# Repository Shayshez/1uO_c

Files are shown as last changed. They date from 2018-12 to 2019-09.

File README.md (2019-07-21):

1u Version (Pulp Logic) of Ornament & Crime, 30HP.

For pcb's and panels: https://pushermanproductions.com/product/plum-audio-1u-ornament-crime-pcb-and-aluminium-panel/

Teensy Assembling (with Supervisor):https://youtu.be/IDsQhNgkL-Y

OLED Screen Assembling: https://youtu.be/ywh_6SPNrSg 

Need help?
Join "Plum Audio DIY first aid" Group:
https://www.facebook.com/groups/PlumAudioDIY

Looking for assembled module?
https://www.plum-audio.com/product-page/1uo-c

** Note for Pusherman v1.1 Pcb's - There is minor silk screen mistake - The Inputs and Outputs not numberd correctly. 
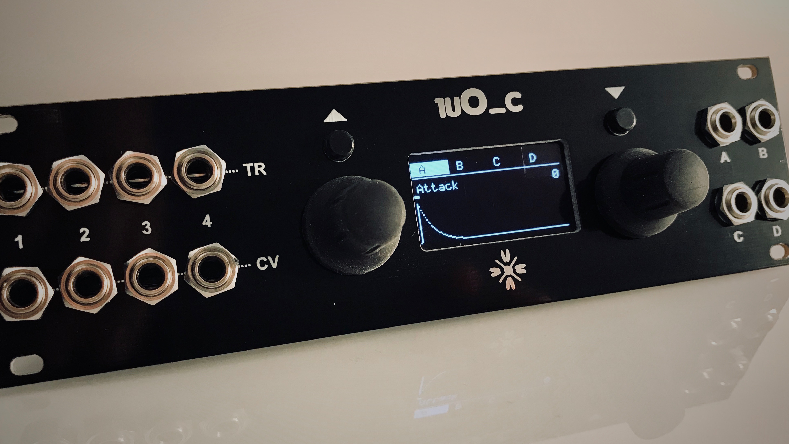
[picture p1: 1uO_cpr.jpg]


1uO_c

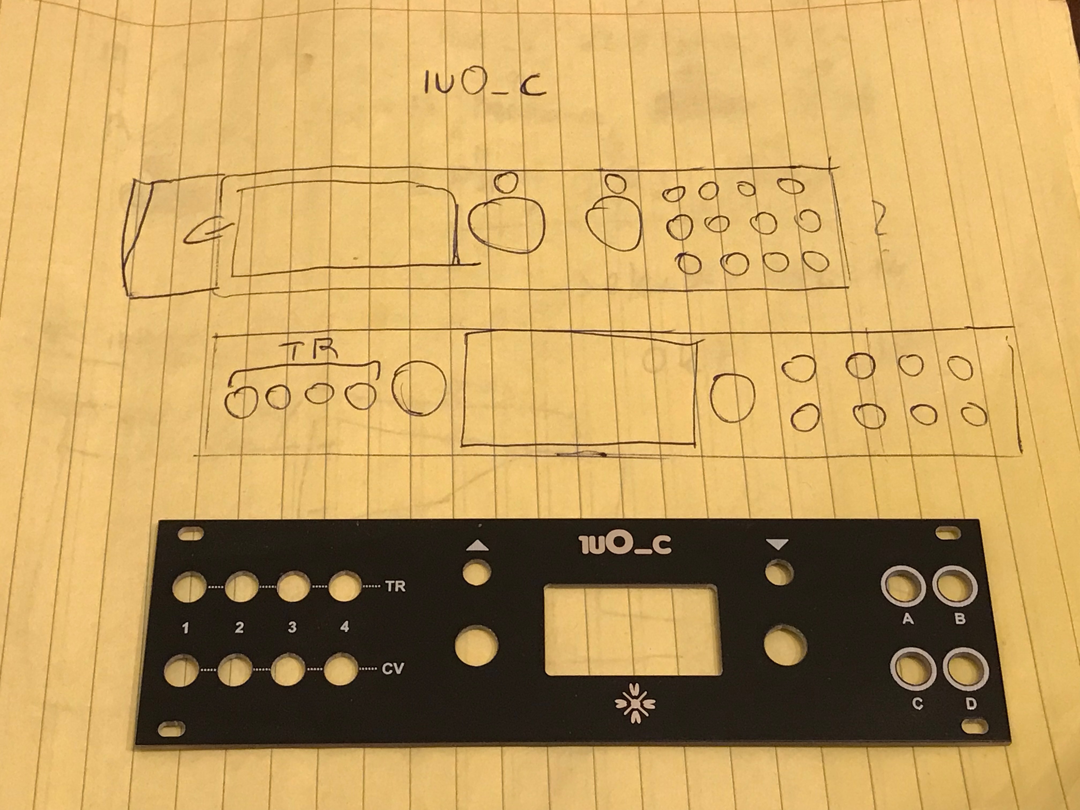
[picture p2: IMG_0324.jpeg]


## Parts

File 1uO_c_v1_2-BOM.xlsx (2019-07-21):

 | Mouser Project: | https://www.mouser.com/ProjectManager/ProjectDetail.aspx?AccessID=c8782e858b
Qty | Value | Device | Package | Parts | Mouser | Description | ALLIED_NUMBER | ALLIED_PRICE-STOCK | ARROW_PART_NUMBER | ARROW_PRICE-STOCK | AVAILABILITY | DESCRIPTION | HEIGHT | MANUFACTURER_NAME | MANUFACTURER_PART_NUMBER | MF | MP | MPN | PACKAGE | PRICE | RS_PART_NUMBER | RS_PRICE-STOCK | SPICEPREFIX | VALUE | WE-NUMBER
4 | 100R | R-EU_R0603 | R0603 | R23, R25, R33, R41 | 603-RC0603FR-07100RL | RESISTOR, European symbol |  |  |  |  |  |  |  |  |  |  |  |  |  |  |  |  | R
4 | 220R | R-EU_R0603 | R0603 | R1, R3, R5, R6 | 603-RC0603FR-07220RL | RESISTOR, European symbol |  |  |  |  |  |  |  |  |  |  |  |  |  |  |  |  | R
2 | 510R | R-EU_R0603 | R0603 | R15, R17 | 603-RC0603FR-07510RL | RESISTOR, European symbol |  |  |  |  |  |  |  |  |  |  |  |  |  |  |  |  | R
1 | 2K | R-EU_R0603 | R0603 | R18 | 603-RC0603FR-102KL | RESISTOR, European symbol |  |  |  |  |  |  |  |  |  |  |  |  |  |  |  |  | R
1 | 10k | R-EU_R0603 | R0603 | R13 | 603-RC0603FR-0710KL | RESISTOR, European symbol |  |  |  |  |  |  |  |  |  |  |  |  |  |  |  |  | R
4 | 24K9 | R-EU_R0603 | R0603 | R9, R10, R11, R12 | 603-RC0603FR-0724K9L | RESISTOR, European symbol |  |  |  |  |  |  |  |  |  |  |  |  |  |  |  |  | R
8 | 33K | R-EU_R0603 | R0603 | R20, R22, R27, R30, R32, R35, R36, R40 | 603-RC0603FR-1333KL | RESISTOR, European symbol |  |  |  |  |  |  |  |  |  |  |  |  |  |  |  |  | R
2 | 47K | R-EU_R0603 | R0603 | R14, R16 | 603-RC0603FR-0747KL | RESISTOR, European symbol |  |  |  |  |  |  |  |  |  |  |  |  |  |  |  |  | R
4 | 75K | R-EU_R0603 | R0603 | R21, R28, R39, R42 | 603-AC0603FR-0775KL | RESISTOR, European symbol |  |  |  |  |  |  |  |  |  |  |  |  |  |  |  |  | R
12 | 100K | R-EU_R0603 | R0603 | R2, R4, R7, R8, R19, R24, R26, R29, R31, R34, R37, R38 | 603-RC0603FR-07100KL | RESISTOR, European symbol |  |  |  |  |  |  |  |  |  |  |  |  |  |  |  |  | R
4 | 18p - 22p | C-EUC0603 C0G/NP0 | C0603 | C5, C6, C11, C12 | 80-C0603C220J5G7411 (https://www.mouser.co.il/ProductDetail/KEMET/C0603C220J5GAC7411?qs=sGAEpiMZZMtJOOgnx%2fXJmejeuawQ%252btGe) | CAPACITOR, European symbol
4 | 330p-560p | C-EUC0603 C0G/NP0 | C0603 | C31, C32, C34, C35 | 581-06035A561G | CAPACITOR, European symbol
15 | 100n | C-EUC0603 | C0603 | C7, C8, C9, C10, C13, C14, C15, C17, C19, C20, C25, C26, C29, C30, C33 | 80-C0603C104K3NAUTO (https://www.mouser.co.il/ProductDetail/KEMET/C0603C104K3NACAUTO) | CAPACITOR, European symbol
4 | 470n | C-EUC0603 | C0603 | C16, C18, C21, C22 | 963-UMK107B7474KA-TR (https://www.mouser.co.il/ProductDetail/TDK/CGA3E3X7R1H474K080AB) | CAPACITOR, European symbol
2 | 1uF | C-EUC0603 | C0603 | C27, C28 | 603-CC603KRX5R8BB105 (https://www.mouser.co.il/ProductDetail/Yageo/CC0603KRX5R8BB105) | CAPACITOR, European symbol
2 | 10uF | C-EUC1206K | C1206K | C23, C24 | 963-TMK316BJ106ML-T (https://www.mouser.co.il/ProductDetail/963-TMK316BJ106ML-T) | CAPACITOR, European symbol
2 | 10uF | CPOL-EUB | PANASONIC_B | C1, C4 | 667-EEE-FK1H100SR (https://www.mouser.co.il/ProductDetail/Panasonic/EEE-FK1H100SR) | POLARIZED CAPACITOR, European symbol |  |  |  |  |  |  |  |  |  |  |  |  |  |  |  |  | C
2 | 22uF | CPOL-EUC | PANASONIC_C | C2, C3 | 667-EEE-FK1H220SR (https://www.mouser.co.il/ProductDetail/Panasonic/EEE-FK1H220SR) | POLARIZED CAPACITOR, European symbol |  |  |  |  |  |  |  |  |  |  |  |  |  |  |  |  | C
1 | 10uH | WE-LQ_1210_744032001 | WE-LQ_M | L1 | 963-LB3218T100K (https://www.mouser.com/Search/ProductDetail.aspx) | SMD Inductor |  |  |  |  |  |  |  |  |  |  |  |  |  |  |  |  |  |  | 744032001/1uH
2 | 1N5819HW | DIODE_DIODE-SOD123 | DIODE_SOD123 | D1, D2 | 621-1N5819HW-F (https://www.mouser.co.il/ProductDetail/Diodes-Incorporated/1N5819HW-7-F) | DIODE
4 | MMBT3904LT1G | SMD-TRANSISTORS-NPN-40V-200MA-MMBT3904LT1G(SOT-23) | SOT-23 | Q1, Q2, Q3, Q4 | 863-MMBT3904LT1G (https://www.mouser.co.il/ProductDetail/ON-Semiconductor/MMBT3904LT1G) | 305010013 |  |  |  |  |  |  |  |  |  |  |  | MMBT3904LT1G |  |  |  |  |  | MMBT3904LT1G
1 | DAC8565IAPW | DAC8565IAPW | SOP65P640X120-16N | U1 | 595-DAC8565IAPW (https://www.mouser.co.il/ProductDetail/Texas-Instruments/DAC8565IAPW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) | Quad Channel DAC |  |  |  |  | Good | 16-Bit, Quad Channel, Ultra-Low Glitch, Voltage Output DAC with 2.5V, 2ppm/C Internal eference 16-TSSOP -40 to 105 |  |  |  | Texas Instruments | DAC8565IAPW |  | TSSOP-16 Texas Instruments | 10.78 USD
1 | LM4040-5V | LM4041B12DBZ | DBZ_R-PDSO-G3 | IC3 | 926-LM4040DIM350NOPB (https://www.mouser.co.il/ProductDetail/Texas-Instruments/LM4040DIM3-50-NOPB) | PRECISION MICROPOWER SHUNT VOLTAGE REFERENCE
2 | TL072D | TL072D | SO08 | IC1, IC2 | 595-TL072CDR (https://www.mouser.co.il/ProductDetail/Texas-Instruments/TL072CDR?qs=sGAEpiMZZMtYFXwiBRPs0zzUsTTH4TUq) | OP AMP
2 | MCP6002SMT | MCP6002SMT | SOIC8 | IC4, IC5 | 579-MCP6002T-I/SN (https://www.mouser.co.il/ProductDetail/Microchip-Technology/MCP6002T-I-SN?qs=sGAEpiMZZMsUzhEcHltCuY6YBL510a4u) | Dual General Op Amp
1 | LD1117S50TR | LD1117S50TR | SOT223 | U3 | 511-LD1117S50 | http://octopart.com/ld1117s50tr-stmicroelectronics-529395 |  |  |  |  | Good | LD1117 Series 1300 mA 5 V Fixed Output Positive Voltage LDO Regulator - SOT-223 |  |  |  | STMicroelectronics | LD1117S50TR |  | SOT-223 STMicroelectronics | 0.19 USD
1 | MIC803-46D2VM3TR | MIC803-46D2VM3TR | SEE DESCRIPOTION -->> | IC6 (https://www.mouser.co.il/ProductDetail/998-MIC803-26D2VM3TR) | 998-MIC803-26D2VM3TR (https://www.mouser.co.il/ProductDetail/998-MIC803-26D2VM3TR) | Teensy Supervisor, You need this only if your case used Linear PSU, Use TH resistor leg to connect RESET hole on 1uT_u PCB to RESET pad on the teensy. In this case it's better to solder the teensy directly to the board. |  |  | MIC803-46D2VM3TR |  |  | 3-pin Microprocessor Supervosor Circui | mm | Micrel | MIC803-46D2VM3TR
1 | ADP150AUJZ-3.3-R7 | ADP150AUJZ-3.3-R7 | SOT95P280X100-5N | U2 | 584-ADP150AUJZ-3.3R7 | IC REG LINEAR 2V 150MA 5TSOT |  |  |  |  | Good | LDO Regulator Pos 2V 0.15A 5-Pin TSOT T/R |  |  |  | Analog Devices | ADP150AUJZ-2.0-R7 |  | TSOT-23 Analog Devices | 0.65 USD
1 | 1X40 Pin Header | Theensy / OLED connector
1 | 2X5 Pin Header | POWER | POWER_10 | J1 | J1
2 | Tact Switch | TACT_SWITCHPTH | TACTILE-PTH | SW1, SW2 | 612-TL1105SP-250 (https://www.mouser.co.il/ProductDetail/612-TL1105SP-250) | Momentary Switch
2 | Tact Switch caps |  |  | SW1, SW2 | 12-1R-BK (https://www.mouser.co.il/ProductDetail/612-1R-BK) | For more colours: https://www.mouser.com/Search/Refine.aspx?FS=TRUE
1 | TEENSY 3.2 | TEENSY_3.2 | TEENSY_3.2 | TEENSY_3.2 |  | https://store.oshpark.com/products/teensy-3-1
1 | OLED | 1U_1.3_OLED | 1U_1.3_OLED | See GitHub link -->> |  | https://github.com/Shayshez/1_3_OLED_FOR_1U
12 | THONKICONN | PJ301_PJ301_THONKICONN | PJ301_WQP_PJ_301M6 | CV1, CV2, CV3, CV4, CV_A, CV_B, CV_C, CV_D, TR1, TR2, TR3, TR4 | Thonk
2 | Encoder | PEC11R | PEC11R-4XXXK-SXXXX | ENC_L, ENC_R | 858-EN11-HSM1BF20 (https://www.mouser.co.il/ProductDetail/858-EN11-HSM1BF20) | Incremental encoder 24 detents 24 pulses Bourns 24 Pulse Incremental Mechanical Rotary Encoder with a 6 mm Flat Shaft (Not Indexed), Through Hole | 70407906 | https://www.alliedelec.com/bourns-pec11r-4215k-s0024/70407906/ | PEC11R-4215K-S0024 | http://uk.rs-online.com/web/p/products/1674651 |  | Incremental encoder 24 detents 24 pulses Bourns 24 Pulse Incremental Mechanical Rotary Encoder with a 6 mm Flat Shaft (Not Indexed), Through Hole | mm | Bourns | PEC11R-4215K-S0024 |  |  |  |  |  | 1674651 | http://uk.rs-online.com/web/p/products/1674651
2 | Knobs | Sifam soft touch Encoder Knob |  |  | Thonk | https://www.thonk.co.uk/shop/sifam-soft-touch-encoder-knobs/
3 | 3M/6MM Nylon standoffs | For screen mounting |  |  |  | https://www.aliexpress.com/item/100pcs-lot-M3-5-6-8-10-12-15-18-20-25-black-Nylon-standoff-3mm/32874390664.html
5 | 3M Nylon screws | For screen mounting |  |  |  | https://www.aliexpress.com/item/Black-100Pcs-Lot-Plastic-Nylon-M3-Hex-Column-Standoff-Spacer-Phillips-Screw-New/32747099724.html

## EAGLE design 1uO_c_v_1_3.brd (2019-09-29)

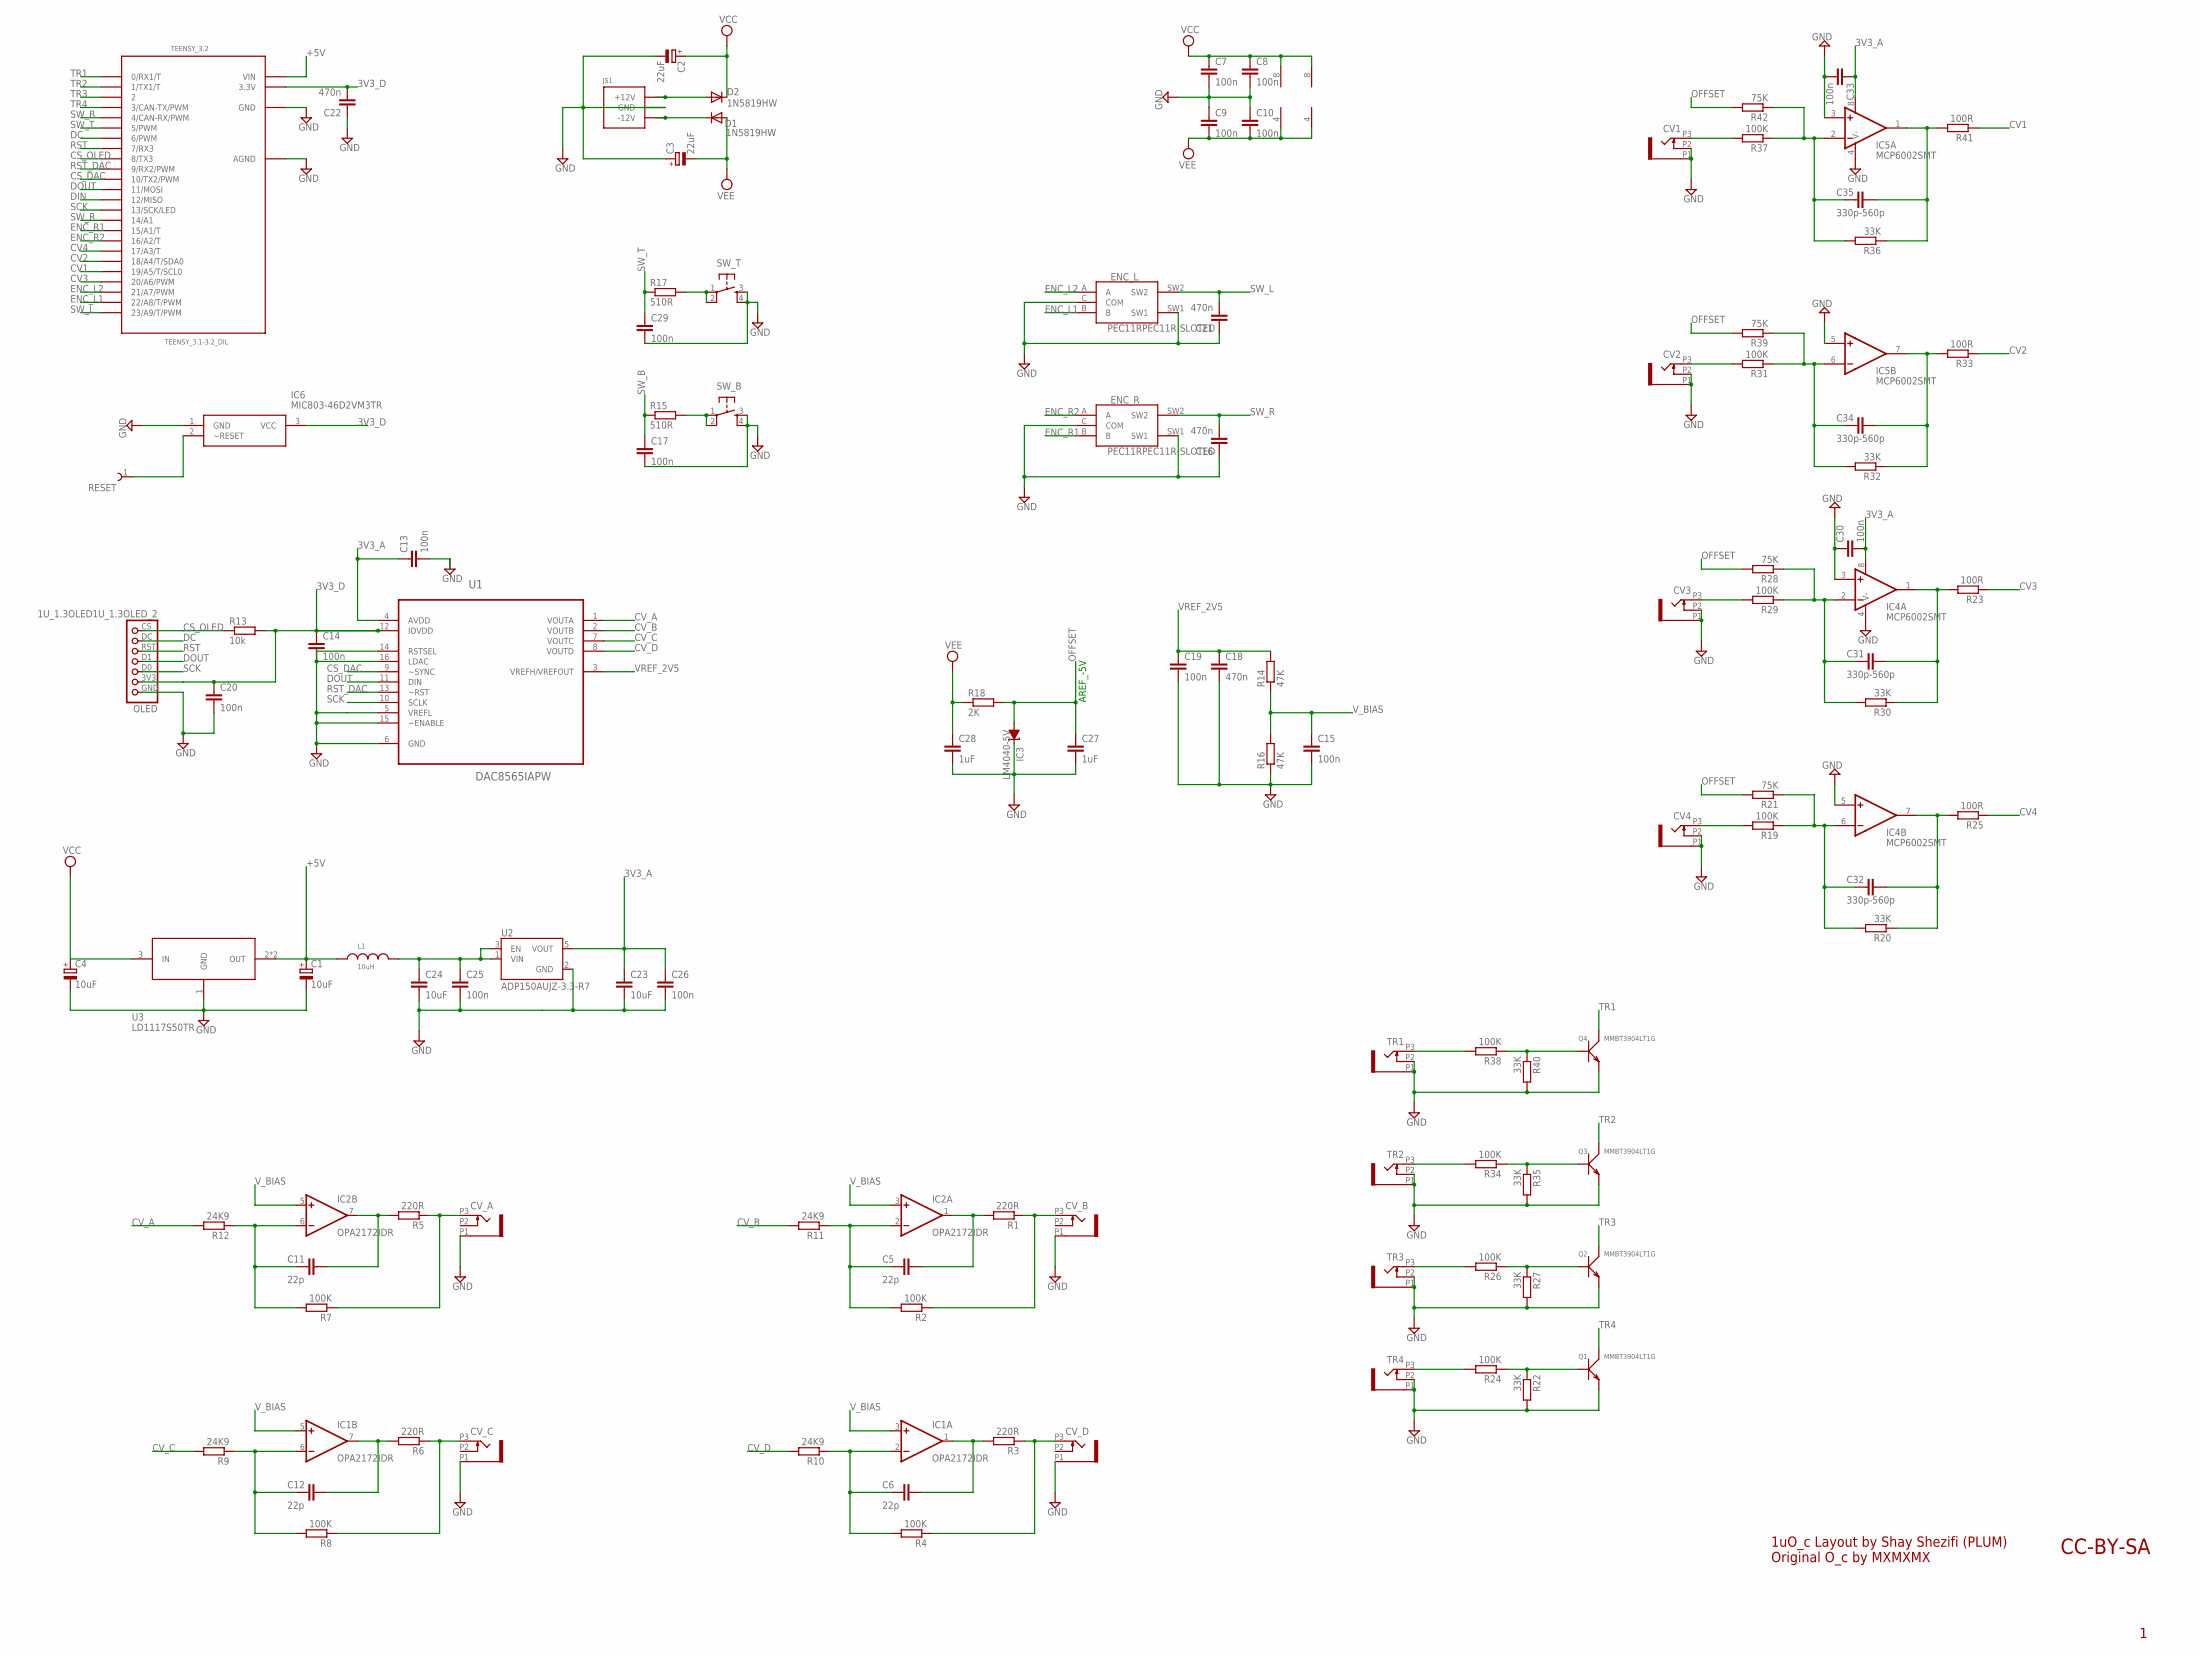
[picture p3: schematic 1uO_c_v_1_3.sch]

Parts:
C1, C4: 10uF; PANASONIC_B
C2, C3: 22uF; PANASONIC_C
C5, C6, C11, C12: 22p; C0603
C7, C8, C9, C10, C13, C14, C15, C17, C19, C20, C25, C26, C29, C30, C33: 100n; C0603
C16, C18, C21, C22: 470n; C0603
C23, C24: 10uF; C1206K
C27, C28: 1uF; C0603
C31, C32, C34, C35: 330p-560p; C0603
CV1, CV2, CV3, CV4: OG-PJ301_PJ301_THONKICONN; OG-PJ301_WQP_PJ_301M6_NO_HOLE
CV_A: OG-PJ301_PJ301_THONKICONN; OG-PJ301_WQP_PJ_301M6_NO_HOLE
CV_B: OG-PJ301_PJ301_THONKICONN; OG-PJ301_WQP_PJ_301M6_NO_HOLE
CV_C: OG-PJ301_PJ301_THONKICONN; OG-PJ301_WQP_PJ_301M6_NO_HOLE
CV_D: OG-PJ301_PJ301_THONKICONN; OG-PJ301_WQP_PJ_301M6_NO_HOLE
D1, D2: 1N5819HW; DIODE_SOD123
ENC_L: PEC11RPEC11R-SLOTED; PEC11R-SLOTED
ENC_R: PEC11RPEC11R-SLOTED; PEC11R-SLOTED
IC1, IC2: OPA2172IDR; SO08
IC3: LM4040-5V; DBZ_R-PDSO-G3
IC4, IC5: MCP6002SMT; SOIC8
IC6: MIC803-46D2VM3TR; SOT95P230X110-3N
J$1: POWER_SIMPLE10; POWER_10
L1: 10uH; WE-LQ_M
OLED: 1U_1.3OLED1U_1.3OLED_2; 1U_1.3OLED_2
Q1, Q2, Q3, Q4: MMBT3904LT1G; SOT-23
R1, R3, R5, R6: 220R; R0603
R2, R4, R7, R8, R19, R24, R26, R29, R31, R34, R37, R38: 100K; R0603
R9, R10, R11, R12: 24K9; R0603
R13: 10k; R0603
R14, R16: 47K; R0603
R15, R17: 510R; R0603
R18: 2K; R0603
R20, R22, R27, R30, R32, R35, R36, R40: 33K; R0603
R21, R28, R39, R42: 75K; R0603
R23, R25, R33, R41: 100R; R0603
RESET: 61300111121
SW_B: TAC_SWITCHPTH; TACTILE-PTH
SW_T: TAC_SWITCHPTH; TACTILE-PTH
TEENSY_3.2: TEENSY_3.1-3.2_DIL; TEENSY_3.0-3.2&LC_DIL
TR1, TR2, TR3, TR4: OG-PJ301_PJ301_THONKICONN; OG-PJ301_WQP_PJ_301M6_NO_HOLE
U1: DAC8565IAPW; SOP65P640X120-16N
U2: ADP150AUJZ-3.3-R7; SOT95P280X100-5N
U3: LD1117S50TR; SOT223

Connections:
3V3_A: C13.1, C23.1, C26.1, C30.2, C33.1, IC4.8 (V+), IC5.8 (V+), U1.4 (AVDD), U2.5 (VOUT)
3V3_D: C14.1, C20.1, C22.2, IC6.3 (VCC), OLED.3V3, R13.2, TEENSY_3.2.3.3V, U1.12 (IOVDD)
+5V: C1.+, L1.1, TEENSY_3.2.VIN, U3.2 (OUT), U3.4 (OUT)
CS_DAC: TEENSY_3.2.10 (10/TX2/PWM), U1.9 (~SYNC)
CS_OLED: OLED.CS, R13.1, TEENSY_3.2.8 (8/TX3)
CV1: R41.1, TEENSY_3.2.19/A5 (19/A5/T/SCL0)
CV2: R33.1, TEENSY_3.2.18/A4 (18/A4/T/SDA0)
CV3: R23.1, TEENSY_3.2.20/A6 (20/A6/PWM)
CV4: R25.1, TEENSY_3.2.17/A3 (17/A3/T)
CV_A: R12.2, U1.1 (VOUTA)
CV_B: R11.2, U1.2 (VOUTB)
CV_C: R9.2, U1.7 (VOUTC)
CV_D: R10.2, U1.8 (VOUTD)
DC: OLED.DC, TEENSY_3.2.6 (6/PWM)
DIN: TEENSY_3.2.12 (12/MISO)
DOUT: OLED.D1, TEENSY_3.2.11 (11/MOSI), U1.11 (DIN)
ENC_L1: ENC_L.B, TEENSY_3.2.22/A8 (22/A8/T/PWM)
ENC_L2: ENC_L.A, TEENSY_3.2.21/A7 (21/A7/PWM)
ENC_R1: ENC_R.B, TEENSY_3.2.15/A1 (15/A1/T)
ENC_R2: ENC_R.A, TEENSY_3.2.16/A2 (16/A2/T)
GND: C1.-, C2.-, C3.+, C4.-, C7.2, C8.2, C9.1, C10.1, C13.2, C14.2, C15.2, C16.1, C17.2, C18.2, C19.2, C20.2, C21.1, C22.1, C23.2, C24.2, C25.2, C26.2, C27.2, C28.2, C29.2, C30.1, C33.2, CV1.P1 (1), CV1.P2 (2), CV2.P1 (1), CV2.P2 (2), CV3.P1 (1), CV3.P2 (2), CV4.P1 (1), CV4.P2 (2), CV_A.P1 (1), CV_B.P1 (1), CV_C.P1 (1), CV_D.P1 (1), ENC_L.C (COM), ENC_L.SW1, ENC_R.C (COM), ENC_R.SW1, IC3.1 (C), IC4.3 (+IN), IC4.4 (V-), IC4.5 (+IN), IC5.3 (+IN), IC5.4 (V-), IC5.5 (+IN), IC6.1 (GND), J$1.3 (GND), J$1.4 (GND), J$1.5 (GND), J$1.6 (GND), J$1.7 (GND), J$1.8 (GND), OLED.GND, Q1.2 (E), Q2.2 (E), Q3.2 (E), Q4.2 (E), R16.1, R22.2, R27.2, R35.2, R40.2, SW_B.3, SW_B.4, SW_T.3, SW_T.4, TEENSY_3.2.AGND, TEENSY_3.2.GND, TR1.P1 (1), TR1.P2 (2), TR2.P1 (1), TR2.P2 (2), TR3.P1 (1), TR3.P2 (2), TR4.P1 (1), TR4.P2 (2), U1.5 (VREFL), U1.6 (GND), U1.14 (RSTSEL), U1.15 (~ENABLE), U1.16 (LDAC), U2.2 (GND), U3.1 (GND)
unnamed: D1.C, J$1.1 (-12V), J$1.2 (-12V)
unnamed: D2.A, J$1.9 (+12V), J$1.10 (+12V)
unnamed: C24.1, C25.1, L1.2, U2.1 (VIN), U2.3 (EN)
unnamed: CV1.P3 (3), R37.2
unnamed: C35.2, IC5.2 (-IN), R36.2, R37.1, R42.1
unnamed: C35.1, IC5.1 (OUT), R36.1, R41.2
unnamed: R17.2, SW_T.1, SW_T.2
unnamed: CV2.P3 (3), R31.2
unnamed: R15.2, SW_B.1, SW_B.2
unnamed: C34.2, IC5.6 (-IN), R31.1, R32.2, R39.1
unnamed: C34.1, IC5.7 (OUT), R32.1, R33.2
unnamed: CV3.P3 (3), R29.2
unnamed: C31.2, IC4.2 (-IN), R28.1, R29.1, R30.2
unnamed: C31.1, IC4.1 (OUT), R23.2, R30.1
unnamed: CV4.P3 (3), R19.2
unnamed: C32.2, IC4.6 (-IN), R19.1, R20.2, R21.1
unnamed: C32.1, IC4.7 (OUT), R20.1, R25.2
unnamed: R38.2, TR1.P3 (3)
unnamed: Q4.1 (B), R38.1, R40.1
unnamed: R34.2, TR2.P3 (3)
unnamed: Q3.1 (B), R34.1, R35.1
unnamed: R26.2, TR3.P3 (3)
unnamed: Q2.1 (B), R26.1, R27.1
unnamed: R24.2, TR4.P3 (3)
unnamed: Q1.1 (B), R22.1, R24.1
unnamed: C5.2, IC2.2 (-IN), R2.2, R11.1
unnamed: C11.2, IC2.6 (-IN), R7.2, R12.1
unnamed: C11.1, IC2.7 (OUT), R5.2
unnamed: CV_A.P3 (3), R5.1, R7.1
unnamed: C5.1, IC2.1 (OUT), R1.2
unnamed: CV_B.P3 (3), R1.1, R2.1
unnamed: C12.2, IC1.6 (-IN), R8.2, R9.1
unnamed: C12.1, IC1.7 (OUT), R6.2
unnamed: CV_C.P3 (3), R6.1, R8.1
unnamed: C6.2, IC1.2 (-IN), R4.2, R10.1
unnamed: C6.1, IC1.1 (OUT), R3.2
unnamed: CV_D.P3 (3), R3.1, R4.1
unnamed: IC6.2 (~RESET), RESET.1
OFFSET: C27.1, IC3.2 (A), R18.2, R21.2, R28.2, R39.2, R42.2
RST: OLED.RST, TEENSY_3.2.7 (7/RX3)
RST_DAC: TEENSY_3.2.9 (9/RX2/PWM), U1.13 (~RST)
SCK: OLED.D0, TEENSY_3.2.13 (13/SCK/LED), U1.10 (SCLK)
SW_B: C17.1, R15.1, TEENSY_3.2.4 (4/CAN-RX/PWM)
SW_L: C21.2, ENC_L.SW2, TEENSY_3.2.23/A9 (23/A9/T/PWM)
SW_R: C16.2, ENC_R.SW2, TEENSY_3.2.14/A0 (14/A1)
SW_T: C29.1, R17.1, TEENSY_3.2.5 (5/PWM)
TR1: Q4.3 (C), TEENSY_3.2.0 (0/RX1/T)
TR2: Q3.3 (C), TEENSY_3.2.1 (1/TX1/T)
TR3: Q2.3 (C), TEENSY_3.2.2
TR4: Q1.3 (C), TEENSY_3.2.3 (3/CAN-TX/PWM)
VCC: C2.+, C4.+, C7.1, C8.1, D2.C, IC1.8 (V+), IC2.8 (V+), U3.3 (IN)
VEE: C3.-, C9.2, C10.2, C28.1, D1.A, IC1.4 (V-), IC2.4 (V-), R18.1
VREF_2V5: C18.1, C19.1, R14.2, U1.3 (VREFH/VREFOUT)
V_BIAS: C15.1, IC1.3 (+IN), IC1.5 (+IN), IC2.3 (+IN), IC2.5 (+IN), R14.1, R16.2

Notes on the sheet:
AREF_-5V
1uO_c Layout by Shay Shezifi (PLUM) Original O_c by MXMXMX
CC-BY-SA

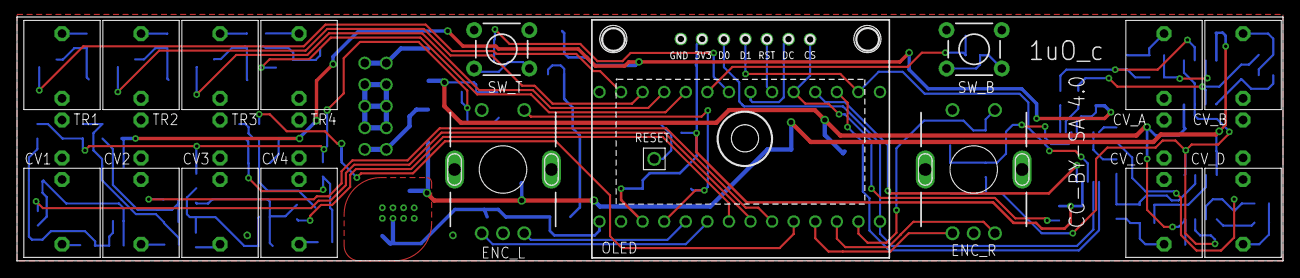
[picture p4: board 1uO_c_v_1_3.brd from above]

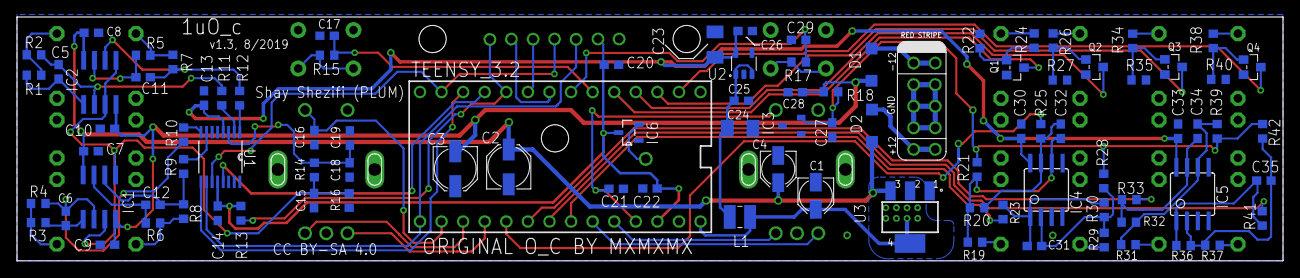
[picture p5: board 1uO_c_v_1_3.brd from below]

Board: 2 copper layers, 149.0 x 28.7 mm, 113 parts (95 on the bottom side), 74 nets.

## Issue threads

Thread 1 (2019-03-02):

Output opamps IC1 and IC2 get very hot when no cables plugged in

Jagmills, 2019-03-02:
Hi!

I think the cause is the output jacks' switches are grounded. When an unconnected cable is plugged in to every output, the ICs are a normal temperature.
The original o_C schematic shows that these pins are not connected.

A solution is to desolder the jacks and remove the switching plate or pin.

Shayshez, 2019-09-29:
Fixed in board v 1.3

Closed 2019-11-25.

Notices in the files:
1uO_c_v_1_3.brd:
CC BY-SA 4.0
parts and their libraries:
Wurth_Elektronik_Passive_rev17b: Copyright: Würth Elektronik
